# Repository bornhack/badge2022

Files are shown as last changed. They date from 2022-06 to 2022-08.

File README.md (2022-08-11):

# BornHack 2022 Game On Badge

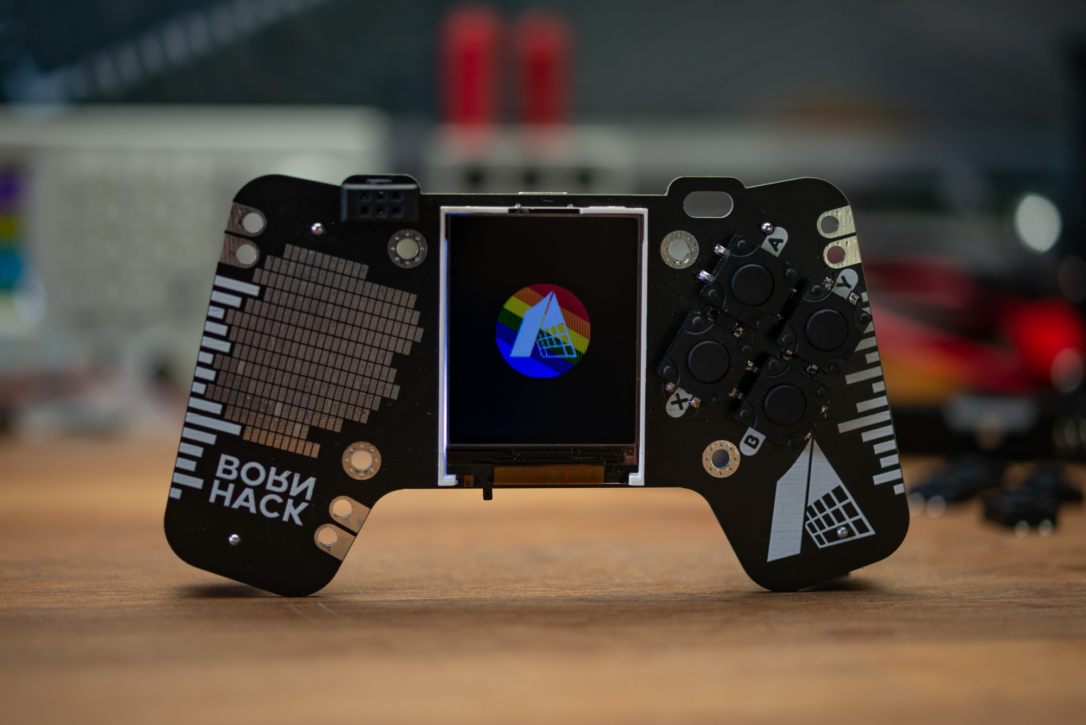
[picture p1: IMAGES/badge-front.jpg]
BornHack 2022 Game On Badge


With this badge we are putting the focus on games. With the shape of a small controller and a color LCD screen in the middle it's ready for a bunch of interesting homebrew games.

This badge uses the RP2040 dualcore Cortex M0+ microcontroller from Raspberry Pi and has 16MB of Quad SPI flash for code and probably also a bit of media files.

The badge will come with [CircuitPython](https://circuitpython.org/) preloaded, for a very low barrier of entry, all you need is a USB-C cable, and your favourite texteditor and you are on your way to your own games.

In addition to screen and navigation buttons, there are are also a standard SAO v1.96bis connector and a Qwiic/Stemma QT connector for interfacing with modules in those eco-systems over I2C.

For those that want to experiment with expanding the badge with a bit more hardware, there is a prototyping area on the left side, maybe for a custom joystick, a preasure sensitive e-textile sensor or something else that works with your game. To interface with the RP2040, there are a few I/O hookup points along the exdge, that support either crocodile test leads, conductive thread or regular wire soldered down, depending on what you are making. Two of those I/O's have analog input capabilities, and there are two more analog inputs in the GPIO1 and GPIO2 pins of the SAO connector, if you need more.

There are also some mounting holes (they fit M3 screws), for mounting an additional add-on board or maybe a 3D printed case. If you want to make your own expansion board, there is [an add-on template](https://github.com/bornhack/badge2022/tree/add-on-template) (it's in the `add-on-template` branch in this repo), that you can open up and customize to your liking before ordering. There will also be some prototyping boards available in the Hardware Hacking Tent at BornHack along with some basic parts, similar to last year.

## CircuitPython restore file

If you flash the board with something else and want to get back to CircuitPython, you can bring the badge into the UF2 bootloader by holding the BOOT button and pressing RESET (you can also hold BOOT when powering on). The badge will then show up as a mass storage device called something like RP2-? which is the build in bootloader and you simply copy over the [firmware.uf2](https://github.com/bornhack/badge2022/raw/hardware/firmware.uf2) file from the root of this repository. The badge will reboot, and you are then back to CircuitPython

The original python files that was on the badge when handed out are in the [cp-init branch](https://github.com/bornhack/badge2022/tree/cp-init)

## Designed in KiCad v6

This board is designed in KiCad v6. To open the project, you will need to install a recent release version or one of the nightly builds, KiCad v5 won't open this design. The [schematic as a PDF](https://github.com/bornhack/badge2022/raw/hardware/schematic.pdf) is included for reference.

## Projects running on the badge

Feel free to submit a PR adding on to this list with your project that runs on the badge.

- [Video player and AM radio transmitter](https://github.com/kbeckmann/bornhack-badge2022-audiovideo) by Konrad Beckmann. See it in action [here](https://twitter.com/kbeckmann/status/1556251282742075393) and [here](https://twitter.com/kbeckmann/status/1555895391463346176).
- [Small adventure hack'n'slash game](https://github.com/MrJavaWolf/BornHack2022Game) by Jens 'JWolf' Larsen. See the [preview here](https://raw.githubusercontent.com/MrJavaWolf/BornHack2022Game/main/resources/teaser-video.mp4).
- [Flappybirds](https://github.com/pietervdvn/BadgeMap/tree/feature/calendar/bornhack) by Pieter Vander Vennet.
- [Pacman](https://github.com/glymphie/bh2022-pacman-game) by Glymphie.

## License

The contents of this repository is released under the following license:

* the "Creative Commons Attribution-ShareAlike 4.0 International License"
  (CC BY-SA 4.0) full text of this license is included in the LICENSE file
  and a copy can also be found at
  [http://creativecommons.org/licenses/by-sa/4.0/](http://creativecommons.org/licenses/by-sa/4.0/)

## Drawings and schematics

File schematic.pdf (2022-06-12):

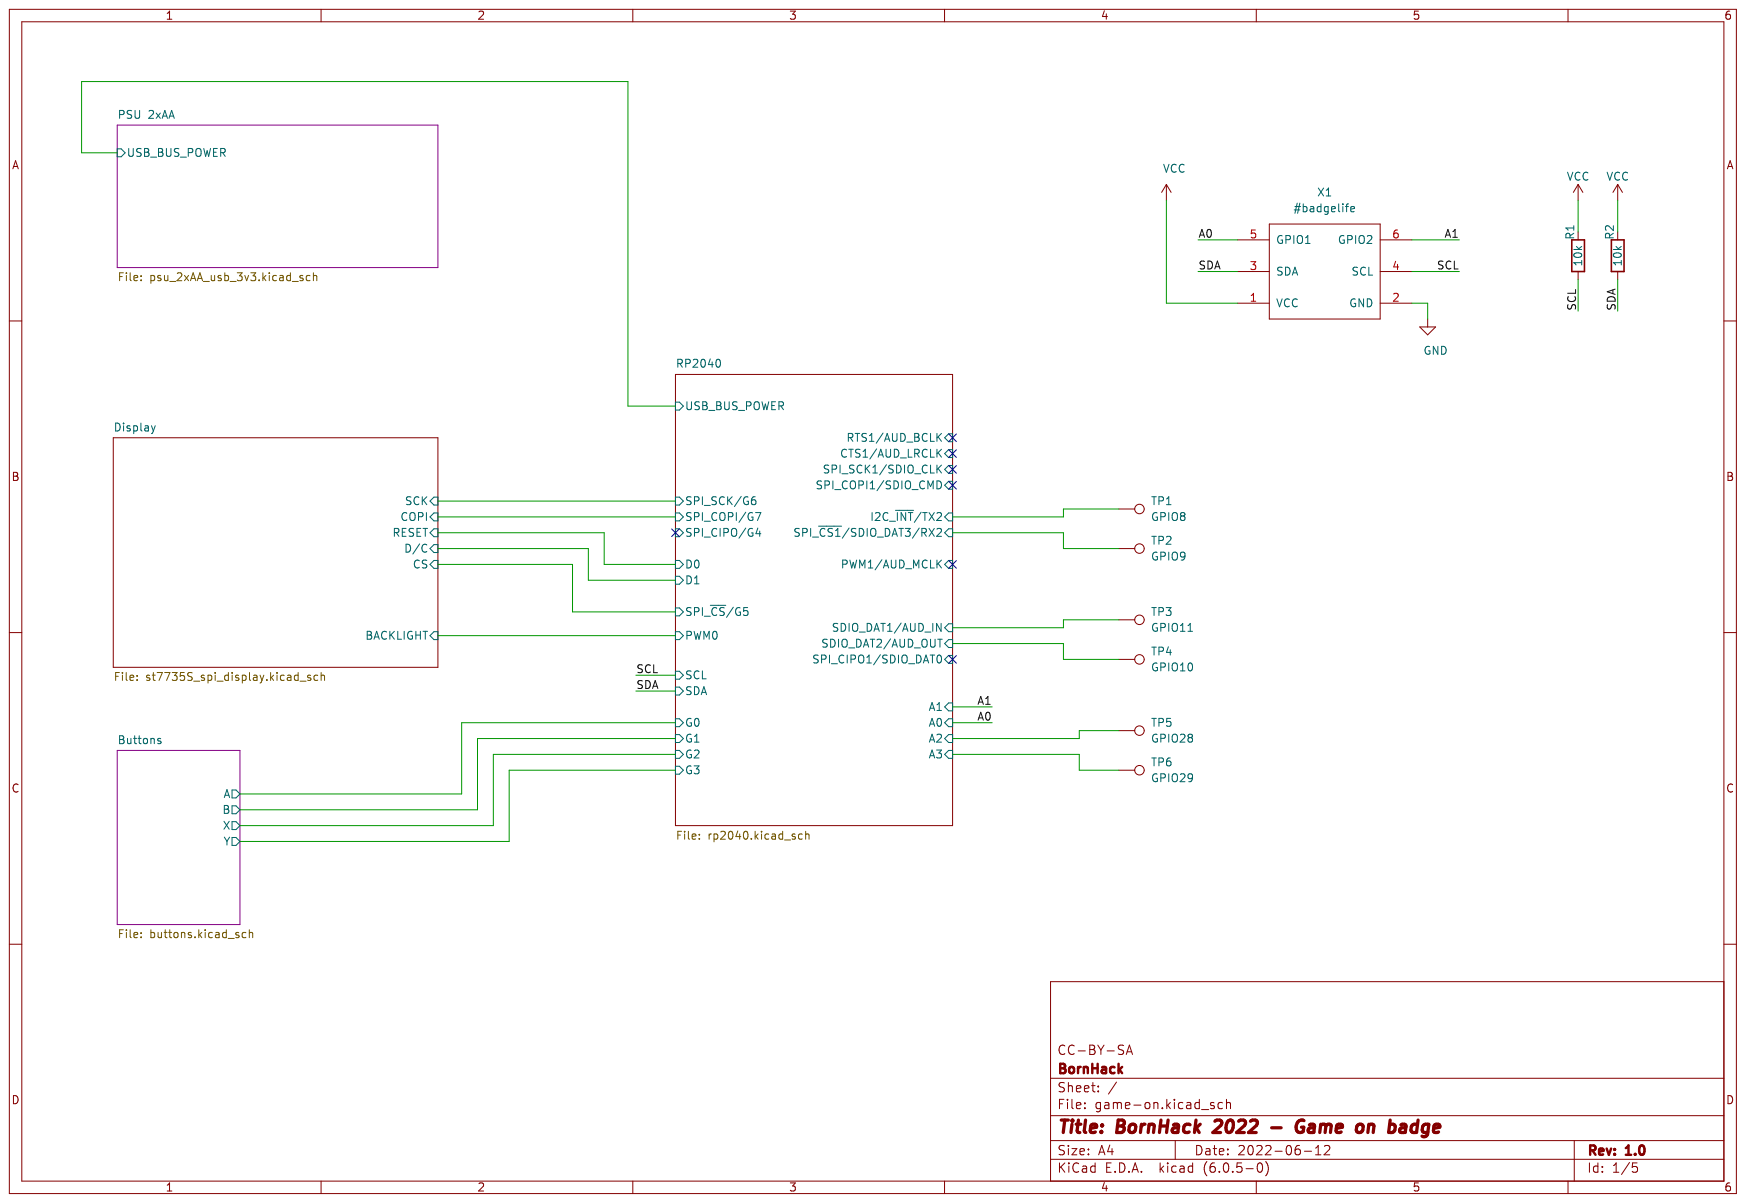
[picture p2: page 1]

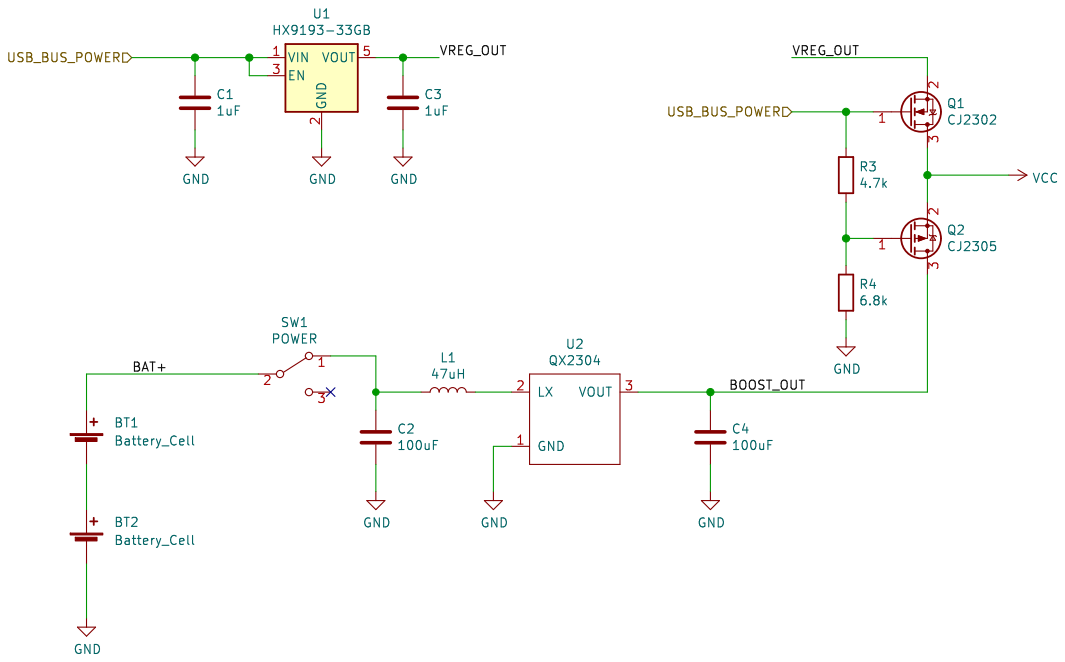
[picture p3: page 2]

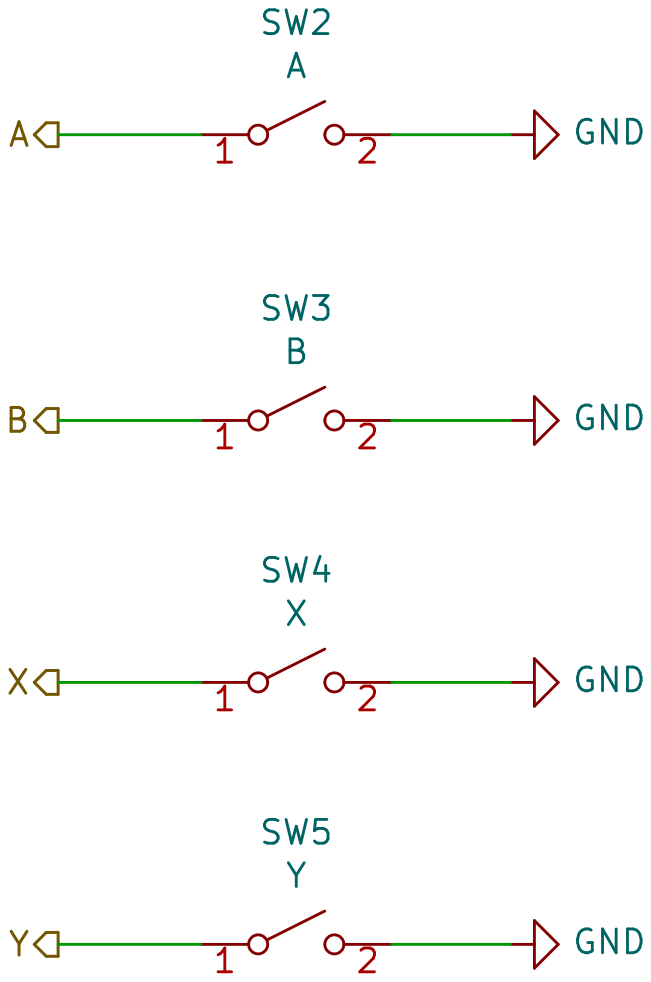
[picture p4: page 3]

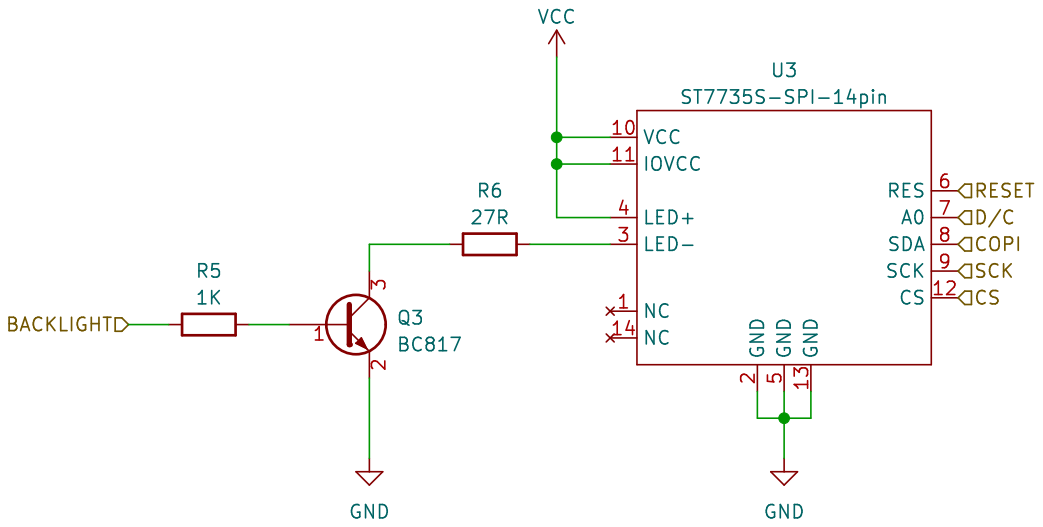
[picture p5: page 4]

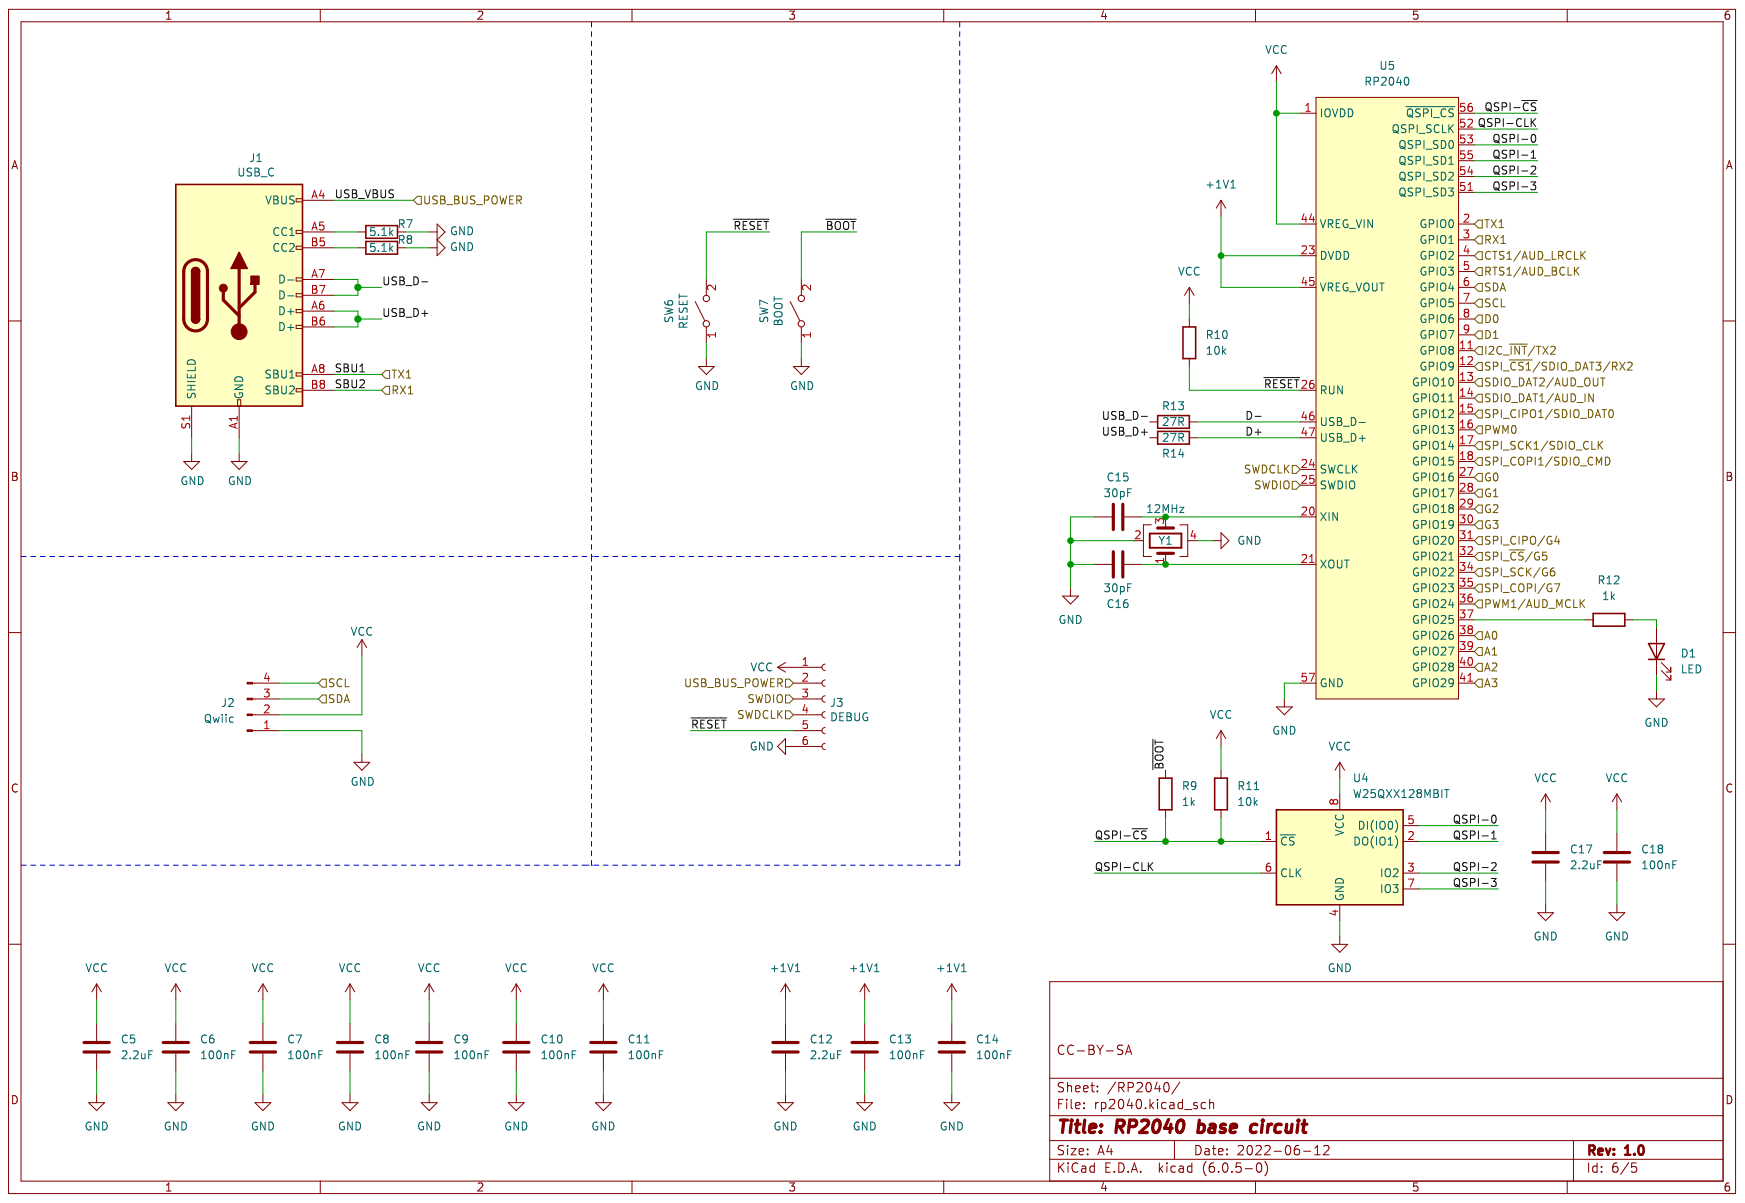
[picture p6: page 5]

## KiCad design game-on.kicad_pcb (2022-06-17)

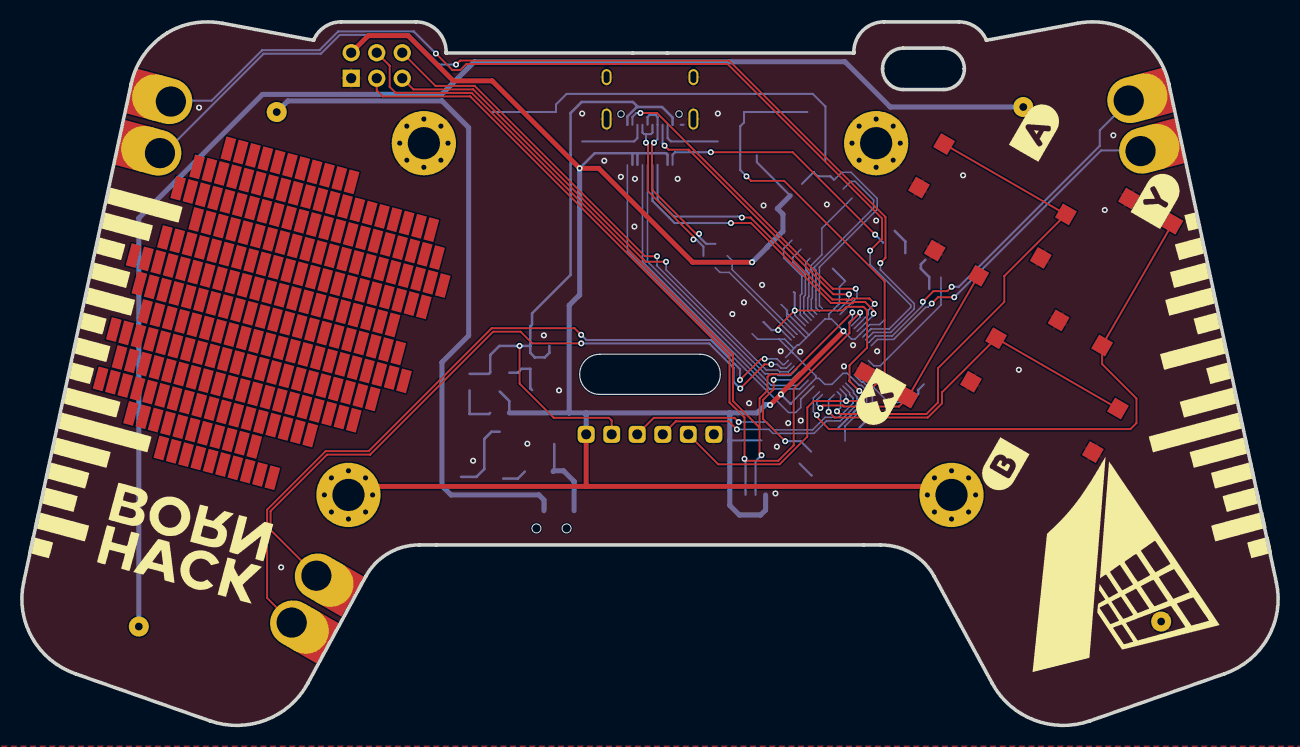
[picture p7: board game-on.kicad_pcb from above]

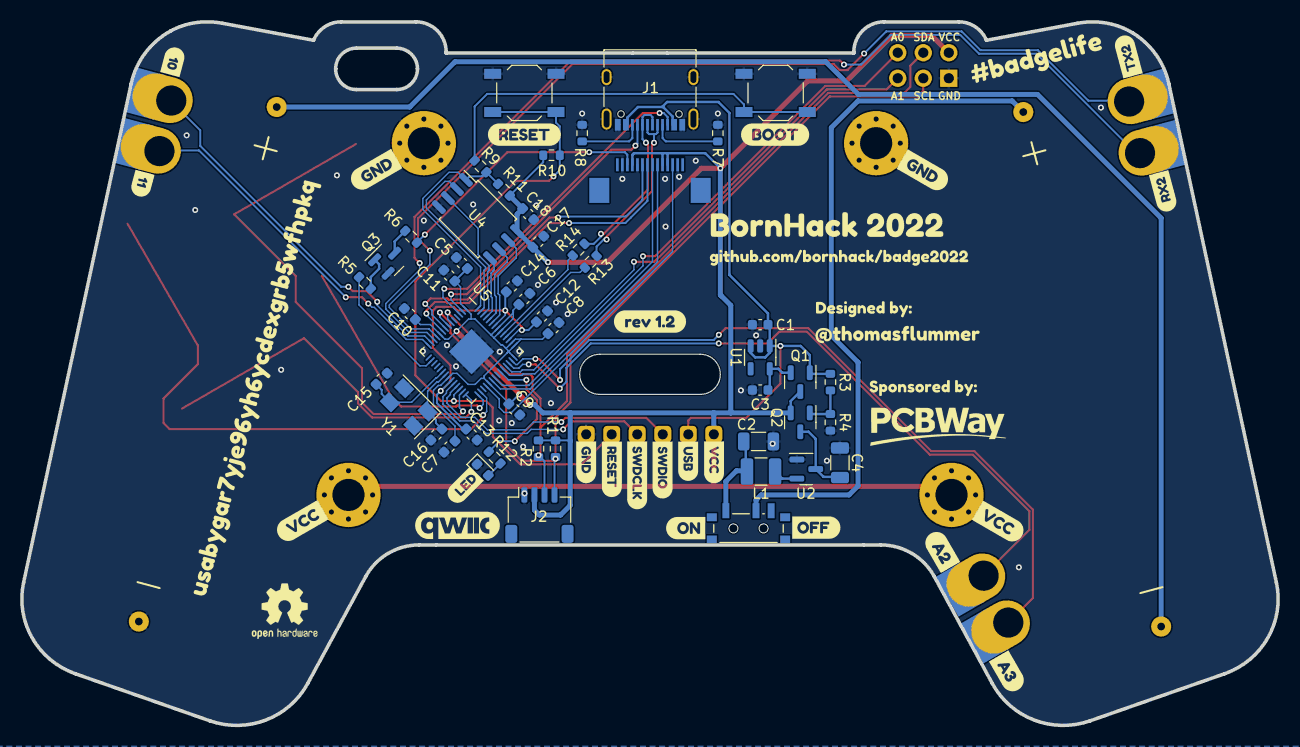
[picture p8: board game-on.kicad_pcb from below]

Board: 2 copper layers, 125.0 x 70.0 mm, 95 parts (78 on the bottom side), 56 nets.

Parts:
BT1, BT2: Battery_Cell; Single_AA
C1, C3: 1uF; C_0603_1608Metric
C2, C4: 100uF; C_1206_3216Metric
C5, C12, C17: 2.2uF; C_0603_1608Metric
C6, C7, C8, C9, C10, C11, C13, C14, C18: 100nF; C_0603_1608Metric
C15, C16: 30pF; C_0603_1608Metric
D1: LED; LED_0603_1608Metric
J1: USB_C; USB_C_Receptacle_XKB_U262-16XN-4BVC11
J2: Qwiic; JST_SH_SM04B-SRSS-TB_1x04-1MP_P1.00mm_Horizontal
J3: DEBUG; PinHeader_1x06_P2.54mm_Vertical
L1: 47uH; L_1210_3225Metric
Q1: CJ2302; SOT-23
Q2: CJ2305; SOT-23
Q3: BC817; SOT-23
R1, R2, R10, R11: 10k; R_0603_1608Metric
R3: 4.7k; R_0603_1608Metric
R4: 6.8k; R_0603_1608Metric
R5: 1K; R_0603_1608Metric
R6, R13, R14: 27R; R_0603_1608Metric
R7, R8: 5.1k; R_0603_1608Metric
R9, R12: 1k; R_0603_1608Metric
SW1: POWER; SW_SPDT_PCM12
SW2: A; 12x12x7.3mm_Tactile_Switch
SW3: B; 12x12x7.3mm_Tactile_Switch
SW4: X; 12x12x7.3mm_Tactile_Switch
SW5: Y; 12x12x7.3mm_Tactile_Switch
SW6: RESET; SW_SPST_TL3342
SW7: BOOT; SW_SPST_TL3342
TP1: GPIO8; PTH_Edge_Proto_Connector
TP2: GPIO9; PTH_Edge_Proto_Connector
TP3: GPIO11; PTH_Edge_Proto_Connector
TP4: GPIO10; PTH_Edge_Proto_Connector
TP5: GPIO28; PTH_Edge_Proto_Connector
TP6: GPIO29; PTH_Edge_Proto_Connector
U1: HX9193-33GB; SOT-23-5
U2: QX2304; SOT-23
U3: ST7735S-SPI-14pin; 1.77inch_128x160_ST7735S_SPI
U4: W25QXX128MBIT; SOIC-8_5.23x5.23mm_P1.27mm
U5: RP2040; QFN-56_EP_7x7_Pitch0.4mm
X1: #badgelife; Badgelife-SAOv169-BADGE-2x3
Y1: 12MHz; Crystal_SMD_5032-4Pin_5.0x3.2mm
kibuzzard-62AC43D4: G***; kibuzzard-62AC43D4
kibuzzard-62AC43F5: G***; kibuzzard-62AC43F5
kibuzzard-62AC44E7: G***; kibuzzard-62AC44E7
kibuzzard-62AC441C: G***; kibuzzard-62AC441C
kibuzzard-62AC5196: G***; kibuzzard-62AC5196
kibuzzard-629F9B54: G***; kibuzzard-629F9B54
kibuzzard-629F9BBE: G***; kibuzzard-629F9BBE
kibuzzard-629F9DE1: G***; kibuzzard-629F9DE1
kibuzzard-629F9DF6: G***; kibuzzard-629F9DF6
kibuzzard-629F9E6D: G***; kibuzzard-629F9E6D
kibuzzard-629F9E81: G***; kibuzzard-629F9E81
kibuzzard-629F97EB: G***; kibuzzard-629F97EB
kibuzzard-629F98B0: G***; kibuzzard-629F98B0
kibuzzard-629F98F3: G***; kibuzzard-629F98F3
kibuzzard-629F99C8: G***; kibuzzard-629F99C8
kibuzzard-629F99E6: G***; kibuzzard-629F99E6
kibuzzard-629F9808: G***; kibuzzard-629F9808
kibuzzard-629F9825: G***; kibuzzard-629F9825
kibuzzard-629F9902: G***; kibuzzard-629F9902
kibuzzard-629FA1A3: G***; kibuzzard-629FA1A3
kibuzzard-629FA2B0: G***; kibuzzard-629FA2B0
kibuzzard-629FA2CB: G***; kibuzzard-629FA2CB
kibuzzard-629FA2E9: G***; kibuzzard-629FA2E9
kibuzzard-629FA297: G***; kibuzzard-629FA297
kibuzzard-629FA844: G***; kibuzzard-629FA844
kibuzzard-629FB3A9: G***; kibuzzard-629FB3A9
kibuzzard-629FB4BE: G***; kibuzzard-629FB4BE
kibuzzard-629FB33D: G***; kibuzzard-629FB33D
kibuzzard-629FB35D: G***; kibuzzard-629FB35D
kibuzzard-629FB38F: G***; kibuzzard-629FB38F
kibuzzard-629FB41C: G***; kibuzzard-629FB41C
kibuzzard-629FB440: G***; kibuzzard-629FB440
kibuzzard-629FB487: G***; kibuzzard-629FB487

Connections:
+1V1: C12.1, C13.1, C14.1, U5.23 (DVDD), U5.45 (VREG_VOUT), U5.50 (DVDD)
/A0: U5.38 (GPIO26), X1.5 (GPIO1)
/A1: U5.39 (GPIO27), X1.6 (GPIO2)
/Buttons/A: SW2.1 (A), U5.27 (GPIO16)
/Buttons/B: SW3.1 (A), U5.28 (GPIO17)
/Buttons/X: SW4.1 (A), U5.29 (GPIO18)
/Buttons/Y: SW5.1 (A), U5.30 (GPIO19)
/Display/BACKLIGHT: R5.2, U5.16 (GPIO13)
/Display/COPI: U3.8 (SDA), U5.35 (GPIO23)
/Display/CS: U3.12 (CS), U5.32 (GPIO21)
/Display/D/C: U3.7 (A0), U5.9 (GPIO7)
/Display/RESET: U3.6 (RES), U5.8 (GPIO6)
/Display/SCK: U3.9 (SCK), U5.34 (GPIO22)
/PSU 2xAA/BAT+: BT1.1 (+), SW1.2 (B)
/PSU 2xAA/BOOST_OUT: C4.1, Q2.3 (D), U2.3 (VOUT)
/PSU 2xAA/VREG_OUT: C3.1, Q1.2 (S), U1.5 (VOUT)
/RP2040/A2: TP5.1, U5.40 (GPIO28)
/RP2040/A3: TP6.1, U5.41 (GPIO29)
/RP2040/D+: R14.2, U5.47 (USB_D+)
/RP2040/D-: R13.2, U5.46 (USB_D-)
/RP2040/I2C_~INT/TX2: TP1.1, U5.11 (GPIO8)
/RP2040/QSPI-0: U4.5 (DI(IO0)), U5.53 (QSPI_SD0)
/RP2040/QSPI-1: U4.2 (DO(IO1)), U5.55 (QSPI_SD1)
/RP2040/QSPI-2: U4.3 (IO2), U5.54 (QSPI_SD2)
/RP2040/QSPI-3: U4.7 (IO3), U5.51 (QSPI_SD3)
/RP2040/QSPI-CLK: U4.6 (CLK), U5.52 (QSPI_SCLK)
/RP2040/QSPI-~CS: R9.2, R11.2, U4.1 (~CS), U5.56 (~QSPI_CS)
/RP2040/SBU1: J1.A8 (SBU1), U5.2 (GPIO0)
/RP2040/SBU2: J1.B8 (SBU2), U5.3 (GPIO1)
/RP2040/SDIO_DAT1/AUD_IN: TP3.1, U5.14 (GPIO11)
/RP2040/SDIO_DAT2/AUD_OUT: TP4.1, U5.13 (GPIO10)
/RP2040/SPI_~CS1/SDIO_DAT3/RX2: TP2.1, U5.12 (GPIO9)
/RP2040/SWDCLK: J3.4, U5.24 (SWCLK)
/RP2040/SWDIO: J3.3, U5.25 (SWDIO)
/RP2040/USB_D+: J1.A6 (D+), J1.B6 (D+), R14.1
/RP2040/USB_D-: J1.A7 (D-), J1.B7 (D-), R13.1
/RP2040/USB_VBUS: C1.1, J1.A4 (VBUS), J1.A9 (VBUS), J1.B4 (VBUS), J1.B9 (VBUS), J3.2, Q1.1 (G), R3.1, U1.1 (VIN), U1.3 (EN)
/RP2040/~BOOT: R9.1, SW7.2 (B)
/RP2040/~RESET: J3.5, R10.2, SW6.2 (B), U5.26 (RUN)
/SCL: J2.4, R1.2, U5.7 (GPIO5), X1.4 (SCL)
/SDA: J2.3, R2.2, U5.6 (GPIO4), X1.3 (SDA)
GND: BT2.2 (-), C1.2, C2.2, C3.2, C4.2, C5.2, C6.2, C7.2, C8.2, C9.2, C10.2, C11.2, C12.2, C13.2, C14.2, C15.1, C16.1, C17.2, C18.2, D1.1 (K), J1.A1 (GND), J1.A12 (GND), J1.B1 (GND), J1.B12 (GND), J1.S1 (SHIELD), J2.1, J3.6, Q3.2 (E), R4.2, R7.1, R8.1, SW2.2 (B), SW3.2 (B), SW4.2 (B), SW5.2 (B), SW6.1 (A), SW7.1 (A), U1.2 (GND), U2.1 (GND), U3.2 (GND), U3.5 (GND), U3.13 (GND), U4.4 (GND), U5.19 (TESTEN), U5.57 (GND), X1.2 (GND), Y1.2, Y1.4
unnamed: BT1.2 (-), BT2.1 (+)
unnamed: C2.1, L1.1, SW1.1 (A)
unnamed: C15.2, U5.20 (XIN), Y1.3
unnamed: C16.2, U5.21 (XOUT), Y1.1
unnamed: D1.2 (A), R12.1
unnamed: J1.A5 (CC1), R7.2
unnamed: J1.B5 (CC2), R8.2
unnamed: L1.2, U2.2 (LX)
unnamed: Q2.1 (G), R3.2, R4.1
unnamed: Q3.1 (B), R5.1
unnamed: Q3.3 (C), R6.2
unnamed: R6.1, U3.3 (LED-)
unnamed: R12.2, U5.37 (GPIO25)
VCC: C5.1, C6.1, C7.1, C8.1, C9.1, C10.1, C11.1, C17.1, C18.1, J2.2, J3.1, Q1.3 (D), Q2.2 (S), R1.1, R2.1, R10.1, R11.1, U3.4 (LED+), U3.10 (VCC), U3.11 (IOVCC), U4.8 (VCC), U5.1 (IOVDD), U5.10 (IOVDD), U5.22 (IOVDD), U5.33 (IOVDD), U5.42 (IOVDD), U5.43 (ADC_AVDD), U5.44 (VREG_VIN), U5.48 (USB_VDD), U5.49 (IOVDD), X1.1 (VCC)

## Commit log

2022-06-12 Tweaked a few values
    [game-on.kicad_pcb, game-on.kicad_sch, rp2040.kicad_sch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]
2022-06-12 Added interactive HTML BOM
2022-06-12 Added PDF schematic
2022-06-17 Adjusted fine pitch pads to allow matte black soldermask between
    Also added a bit of silkscreen tweaks
    [game-on.kicad_pcb]
